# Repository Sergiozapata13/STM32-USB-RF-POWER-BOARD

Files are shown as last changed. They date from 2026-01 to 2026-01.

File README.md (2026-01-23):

# STM32-USB-RF-POWER-BOARD

## Overview
STM32-based embedded board integrating USB, RF transceiver, and regulated power supply.
Designed in KiCad with focus on signal integrity, power distribution, EMI mitigation, and
robust hardware design practices.

The project demonstrates a complete PCB design workflow, from system architecture
definition and schematic design to PCB layout and manufacturability review.

---

## System Architecture
The board integrates the following functional blocks:

- STM32 microcontroller
- USB interface for power and data communication
- nRF24L01+ 2.4 GHz RF transceiver
- Regulated 3.3 V power supply derived from USB
- SWD interface for programming and debugging

---

## Power Architecture

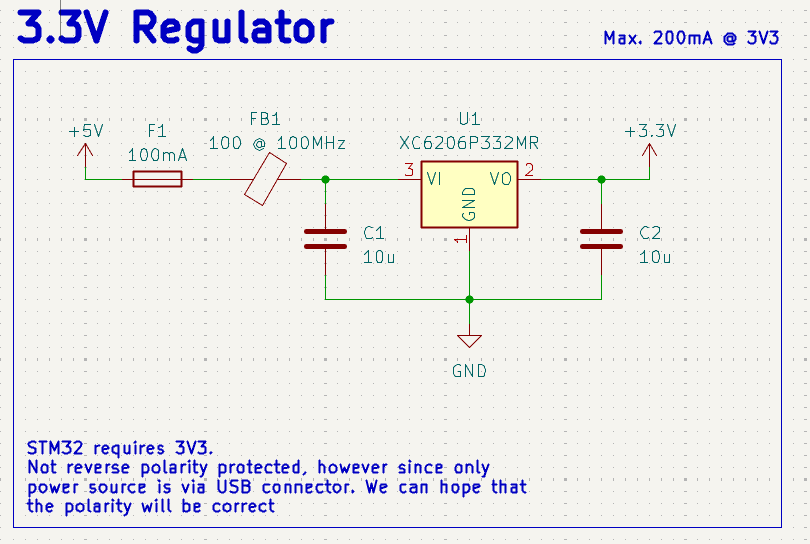
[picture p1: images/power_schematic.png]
Power architecture schematic


The board is powered exclusively from the USB 5 V rail. Input protection is provided
by a resettable fuse (100 mA) and a ferrite bead (100 Ω @ 100 MHz) to limit overcurrent
conditions and attenuate high-frequency noise coming from the USB source.

A low-dropout linear regulator (XC6206P332MR) is used to generate the 3.3 V supply
required by the STM32 microcontroller and the RF transceiver. This regulator was
selected due to its low noise characteristics and simplicity, which are well suited
for low-current embedded applications (up to 200 mA).

Bulk capacitors are placed at both the regulator input and output to ensure stability
and reduce supply ripple. Reverse polarity protection was intentionally omitted, as the
USB connector is the only intended power source for the board.

---

## USB Design

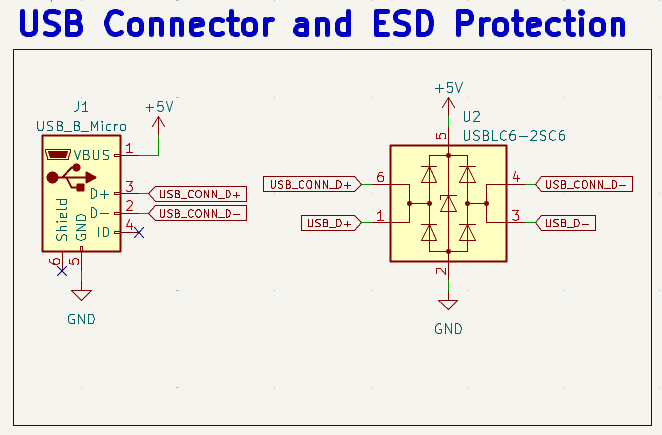
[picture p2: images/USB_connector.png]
USB connector and ESD protection


The USB interface is implemented using a Micro-USB connector and provides both power
and data connectivity. The VBUS line is used as the sole power source for the board.

Electrostatic discharge (ESD) protection is provided by a USBLC6-2SC6 device placed
between the USB connector and the microcontroller. This device protects the D+ and D−
lines against ESD events while preserving signal integrity.

USB differential data lines are routed as a matched pair and clearly labeled to support
controlled impedance routing during PCB layout. Protection components are placed close
to the connector to minimize trace length and reduce exposure to ESD events.

---

## RF Design

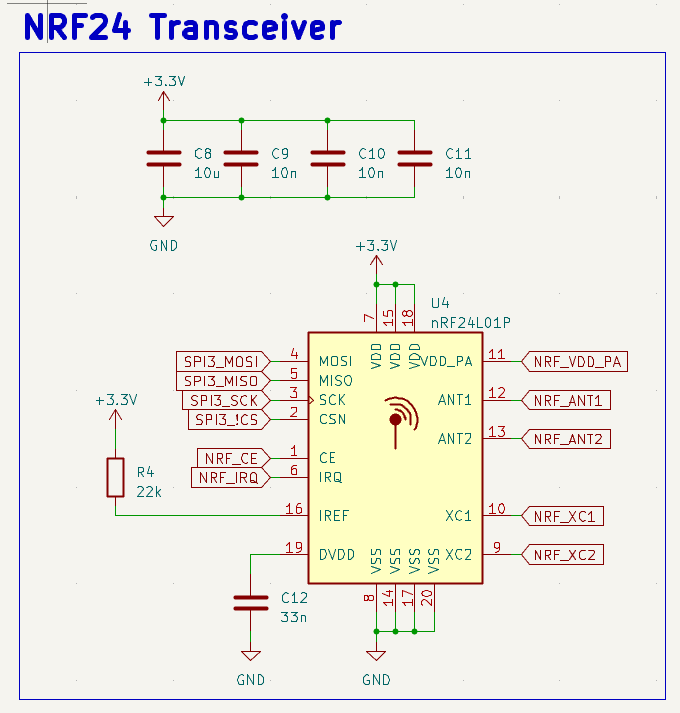
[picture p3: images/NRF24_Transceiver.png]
NRF24 transceiver schematic


The RF subsystem is based on the nRF24L01+ 2.4 GHz transceiver, interfaced with the STM32
microcontroller through an SPI interface. The device is powered from the 3.3 V rail,
with dedicated local decoupling capacitors placed close to the VDD and VDD_PA pins to
ensure stable RF operation.

Special attention was given to power integrity for the RF section by providing adequate
bulk and high-frequency decoupling and following manufacturer reference design
guidelines.

### Antenna Matching Network

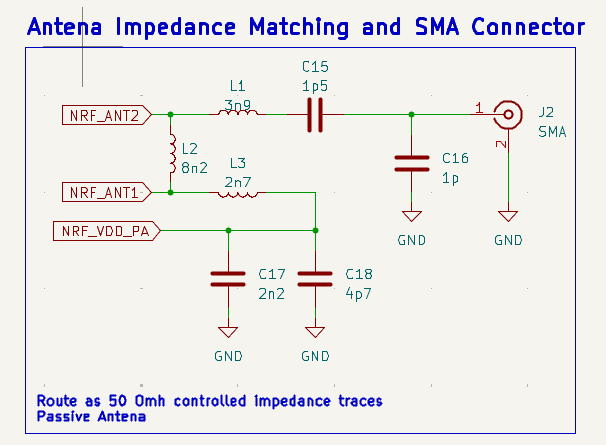
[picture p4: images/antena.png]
Antenna impedance matching network


The RF output is routed through a discrete impedance matching network before reaching
an SMA connector. The matching network is implemented using lumped inductors and
capacitors, allowing flexibility for tuning during bring-up or testing.

The RF trace is intended to be routed as a 50 Ω controlled-impedance transmission line.
Component placement and routing were optimized to keep the RF path as short and direct
as possible, minimizing losses and parasitic effects.

### RF Crystal Oscillator

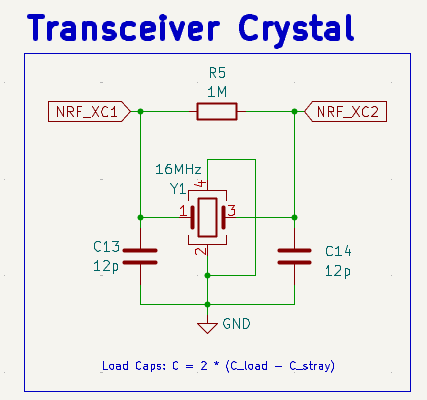
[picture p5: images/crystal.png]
RF crystal oscillator


A dedicated 16 MHz crystal oscillator is used for the RF transceiver. Load capacitors
were selected based on the required load capacitance and estimated stray capacitance
of the PCB layout. A parallel resistor is included to aid oscillator startup and
improve stability.

Crystal components are placed close to the transceiver pins with short, symmetric
traces to minimize phase noise and sensitivity to external interference.

---

## PCB Layout Strategy

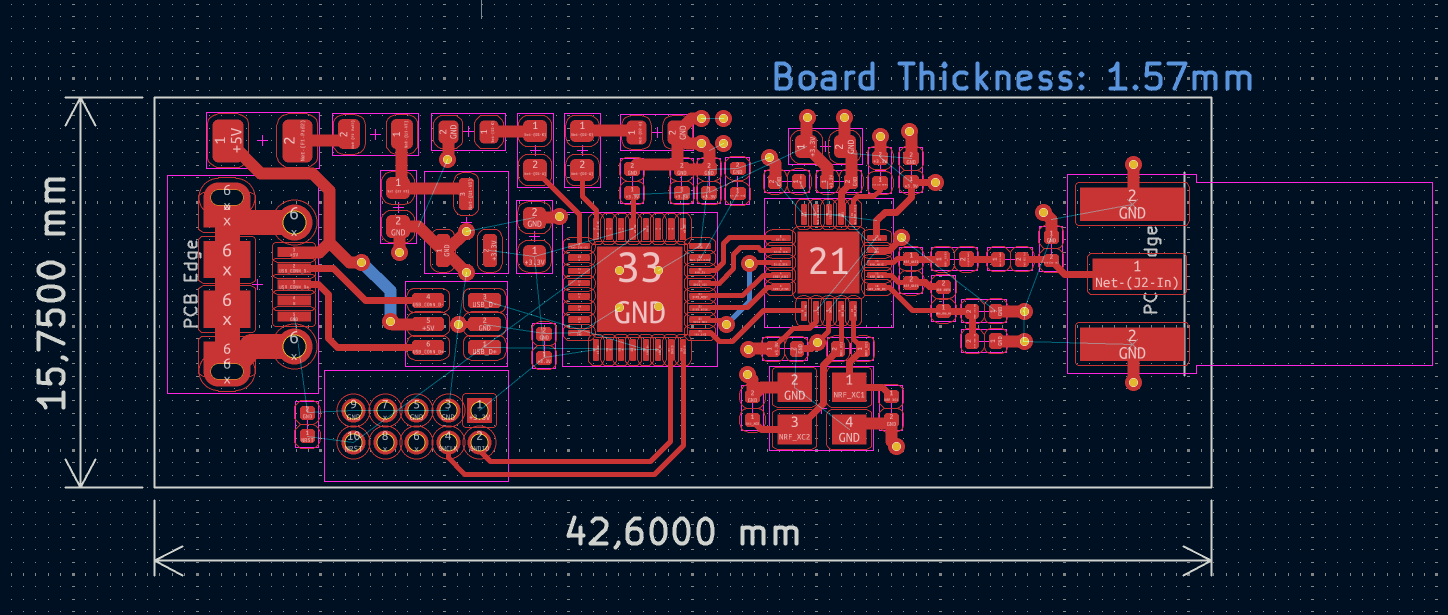
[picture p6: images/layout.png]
PCB layout overview


The PCB layout was developed with emphasis on signal integrity, power distribution,
and noise isolation between digital, RF, and power domains. Component placement was
driven by functional grouping, minimizing critical trace lengths and optimizing return
current paths.

High-frequency and noise-sensitive components, such as the RF transceiver and its
matching network, are placed close together to reduce parasitic effects. Power-related
components are grouped to form compact current loops, reducing EMI and voltage ripple.

USB differential pairs are routed together with consistent spacing and length matching,
and ground continuity is maintained under high-speed signals to ensure a clear return
path.

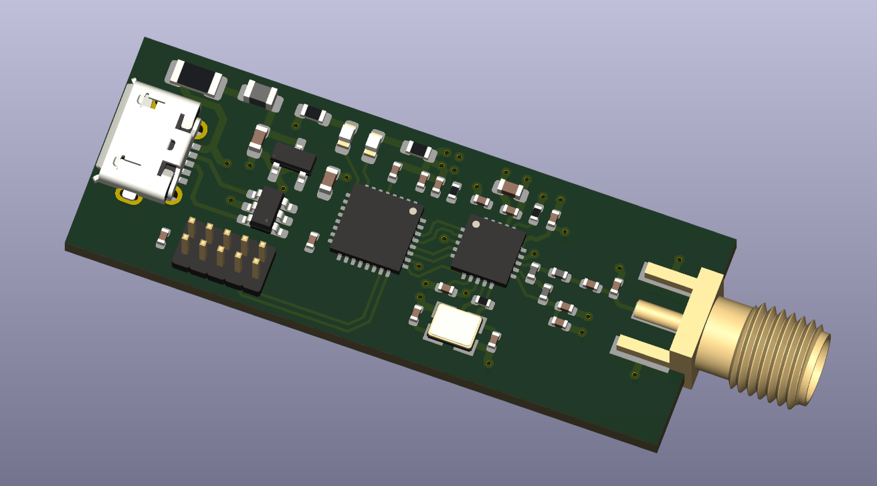
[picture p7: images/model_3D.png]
3D view of the assembled PCB


A compact board outline was selected to balance mechanical constraints, routing density,
and manufacturability.

---

## Hardware Validation and Design Status

The PCB was fully designed and reviewed at schematic and layout level; however, the
board was not manufactured or assembled.

Design validation focused on schematic correctness, component selection, and layout
best practices. Electrical rules checks (ERC) and design rule checks (DRC) were used to
verify connectivity, clearance, and manufacturability constraints.

The design is considered ready for fabrication. A bring-up and validation plan was
defined, including power rail verification, SWD programming, USB enumeration, and basic
RF communication tests.

Although physical validation was not performed, the project demonstrates a complete
end-to-end PCB design workflow, from system architecture definition to layout completion.

---

## Tools
- KiCad
- STM32CubeMX (pinout and reference configuration)

---

## Project Status
- Schematic and PCB layout completed
- Design reviewed with ERC/DRC verification
- Ready for fabrication

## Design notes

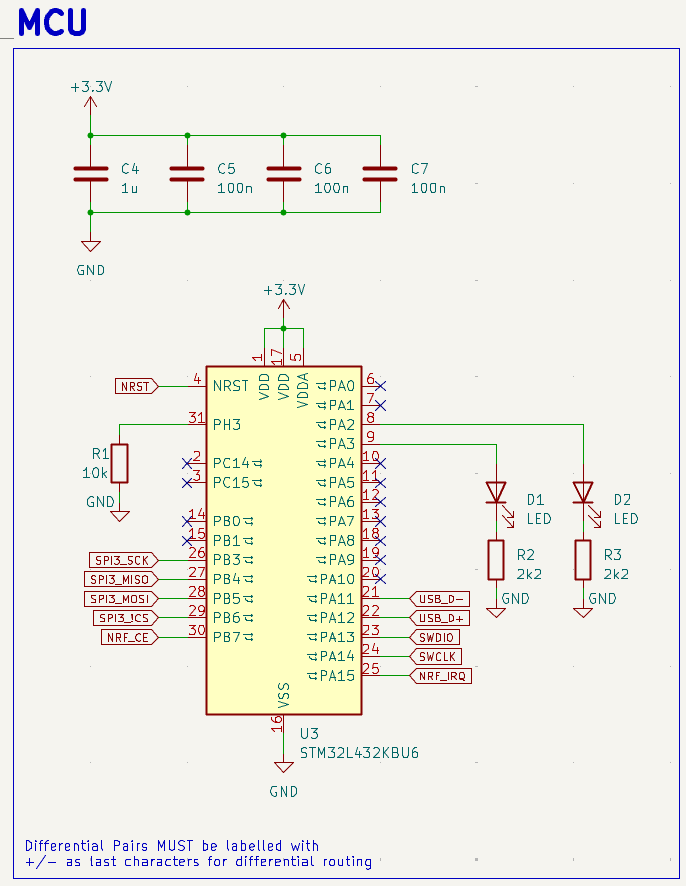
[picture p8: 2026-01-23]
images/MCU.png

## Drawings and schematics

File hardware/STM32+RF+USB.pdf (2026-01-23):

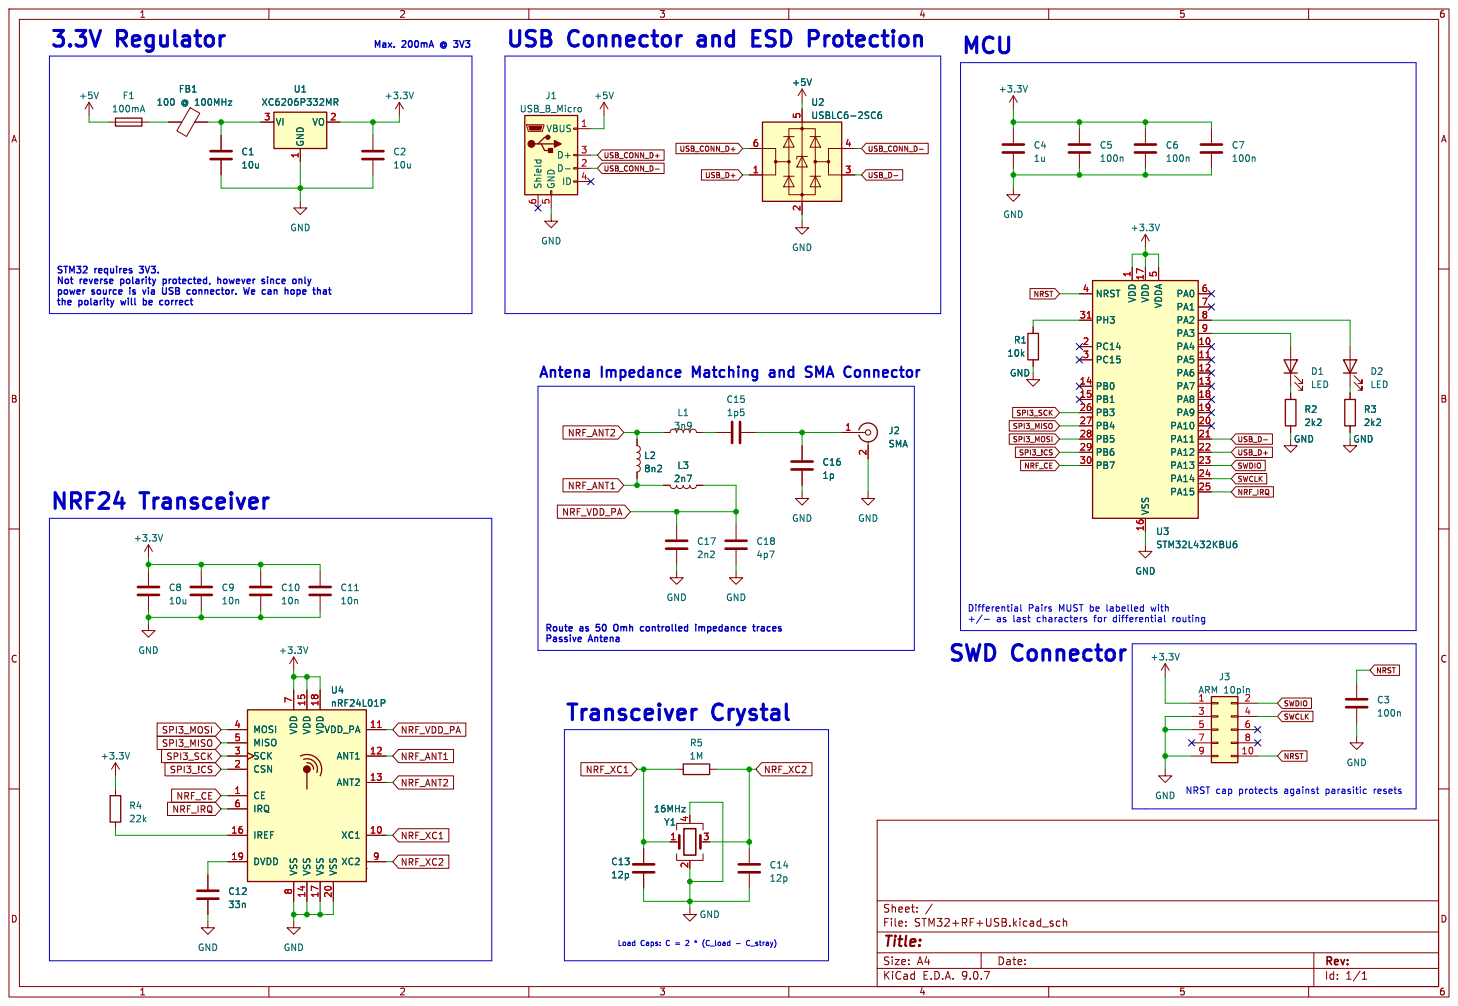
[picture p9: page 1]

USB Connector and ESD Protection

SPI3_!CS STM32 requires 3V3. Not reverse polarity protected, however since only power source is via USB connector. We can hope that

the polarity will be correct NRF24 Transceiver

8 VDD 15 VSS 14 VDD 18 VSS 17 VSS 20 VDD_PA 11 ANT1 12 ANT2 13 XC1 10 XC2 9 C12

8 VDD 15 VSS 14 VDD 18 VSS 17 VSS 20 VDD_PA 11 ANT1 12 ANT2 13 XC1 10 XC2 9 U4

Id: 1/1 Title: File: STM32+RF+USB.kicad_sch Sheet: /

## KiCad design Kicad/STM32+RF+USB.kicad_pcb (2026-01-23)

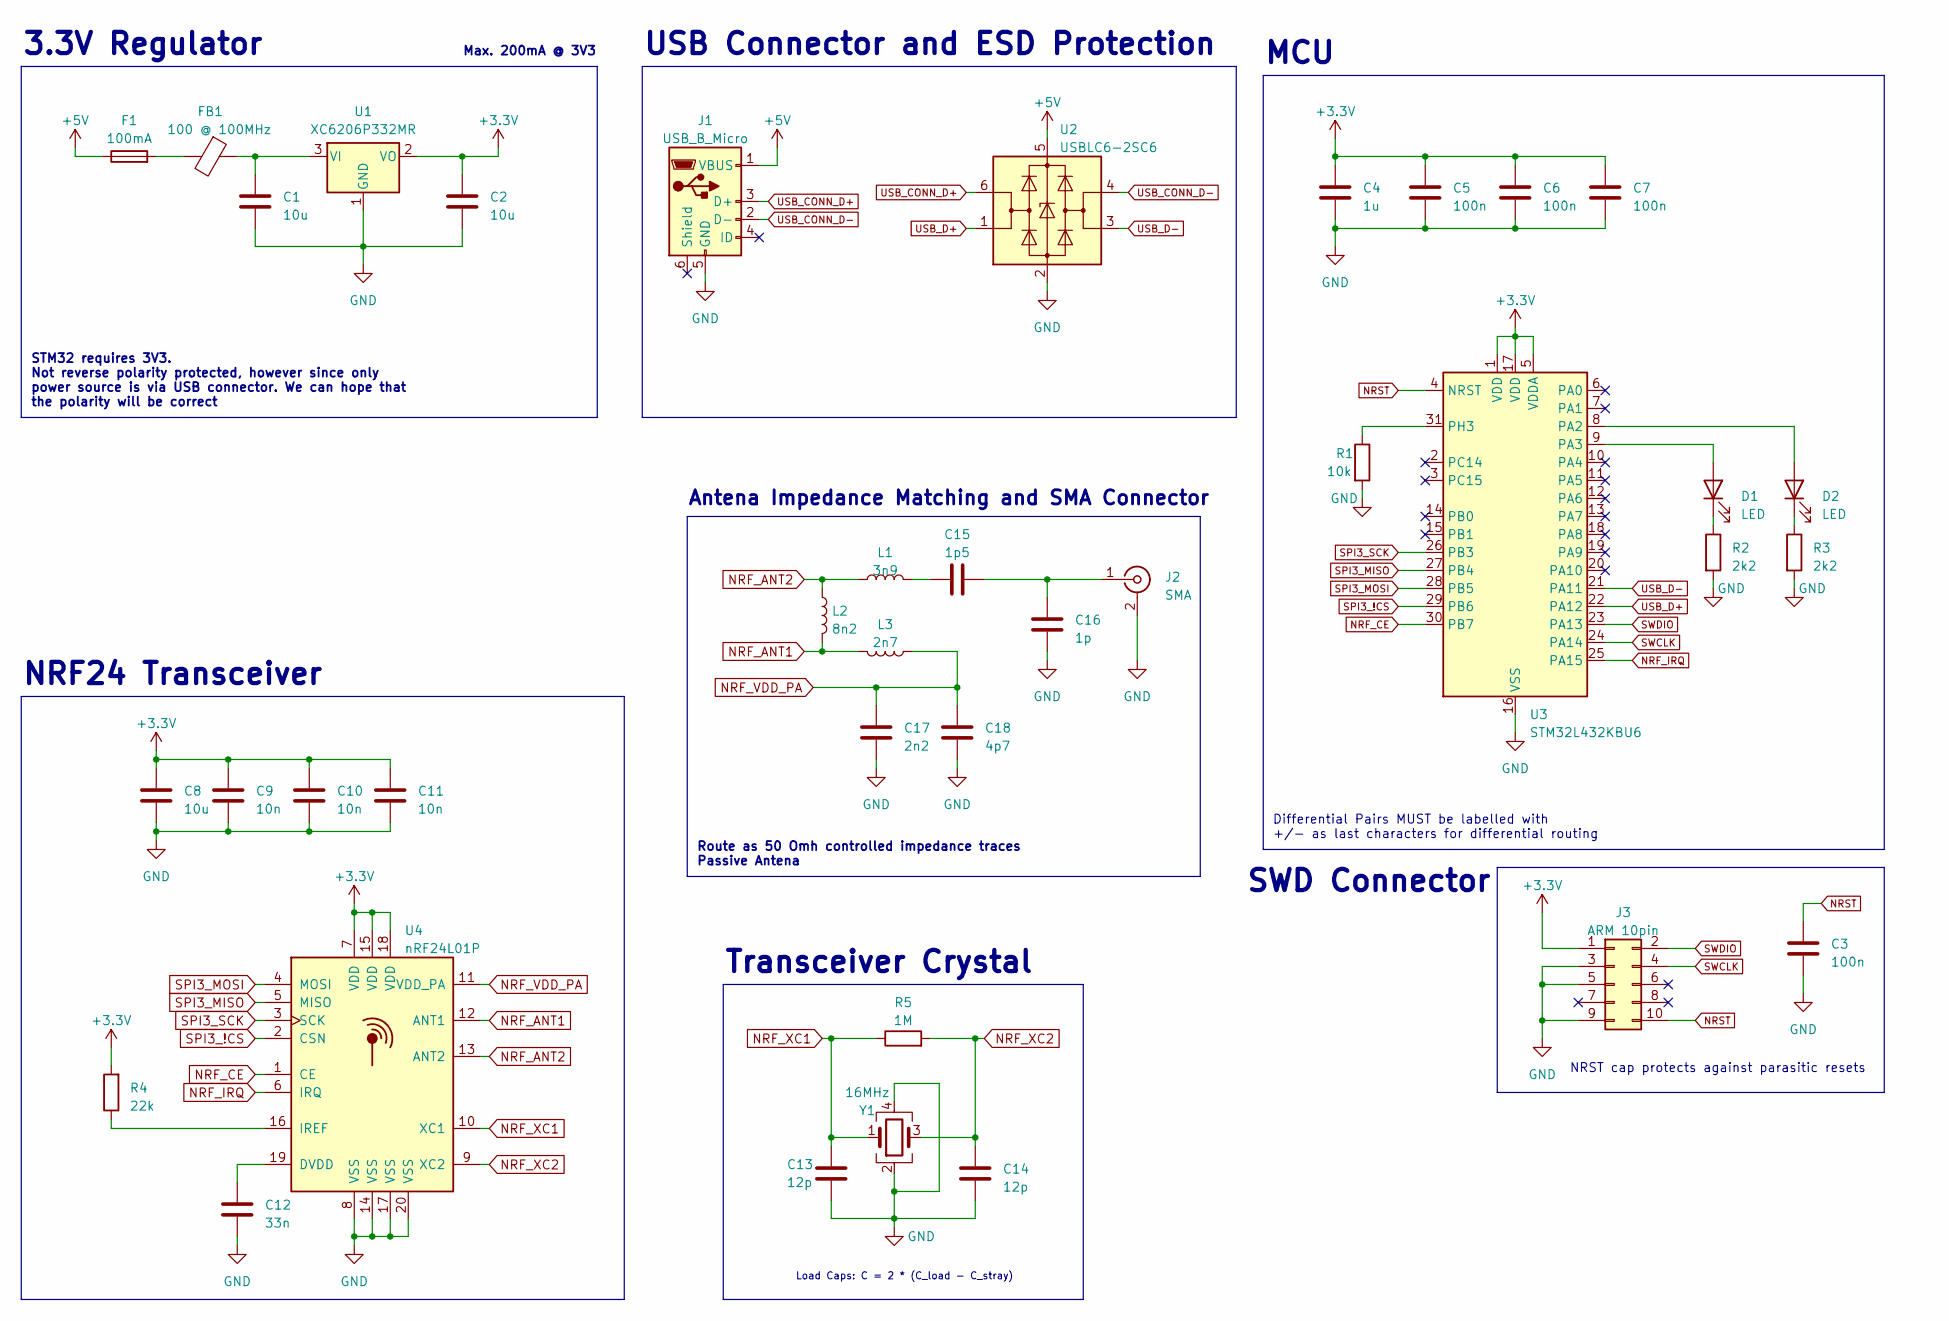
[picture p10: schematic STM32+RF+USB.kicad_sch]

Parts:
C1, C2, C8: 10u; C_0603_1608Metric
C3, C5, C6, C7: 100n; C_0402_1005Metric
C4: 1u; C_0402_1005Metric
C9, C10, C11: 10n; C_0402_1005Metric
C12: 33n; C_0402_1005Metric
C13, C14: 12p; C_0402_1005Metric
C15: 1p5; C_0402_1005Metric
C16: 1p; C_0402_1005Metric
C17: 2n2; C_0402_1005Metric
C18: 4p7; C_0402_1005Metric
D1, D2: LED; LED_0603_1608Metric
F1: 100mA; Fuse_1206_3216Metric
FB1: 100 @ 100MHz; L_0805_2012Metric
J1: USB_B_Micro; USB_Micro-B_Molex-105017-0001
J2: SMA; SMA_Samtec_SMA-J-P-X-ST-EM1_EdgeMount
J3: ARM 10pin; PinHeader_2x05_P1.27mm_Vertical
L1: 3n9; L_0402_1005Metric
L2: 8n2; L_0402_1005Metric
L3: 2n7; L_0402_1005Metric
R1: 10k; R_0402_1005Metric
R2, R3: 2k2; R_0603_1608Metric
R4: 22k; R_0402_1005Metric
R5: 1M; R_0402_1005Metric
U1: XC6206P332MR; SOT-23-3
U2: USBLC6-2SC6; SOT-23-6
U3: STM32L432KBU6; QFN-32-1EP_5x5mm_P0.5mm_EP3.45x3.45mm
U4: nRF24L01P; QFN-20-1EP_4x4mm_P0.5mm_EP2.5x2.5mm
Y1: 16MHz; Crystal_SMD_3225-4Pin_3.2x2.5mm

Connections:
+3.3V: C2.1, C4.1, C5.1, C6.1, C7.1, C8.1, C9.1, C10.1, C11.1, J3.1, R4.2, U1.2 (VO), U3.1 (VDD), U3.5 (VDDA), U3.17 (VDD), U4.7 (VDD), U4.15 (VDD), U4.18 (VDD)
+5V: F1.1, J1.1 (VBUS), U2.5 (VBUS)
GND: C1.2, C2.2, C3.2, C4.2, C5.2, C6.2, C7.2, C8.2, C9.2, C10.2, C11.2, C12.2, C13.2, C14.2, C16.1, C17.1, C18.1, J1.5 (GND), J2.2 (Ext), J3.3, J3.5, J3.9, R1.2, R2.2, R3.2, U1.1 (GND), U2.2 (GND), U3.16 (VSS), U3.32 (VSS), U3.33 (VSS), U4.8 (VSS), U4.14 (VSS), U4.17 (VSS), U4.20 (VSS), Y1.2, Y1.4
NRF_ANT1: L2.2, L3.2, U4.12 (ANT1)
NRF_ANT2: L1.1, L2.1, U4.13 (ANT2)
NRF_CE: U3.30 (PB7), U4.1 (CE)
NRF_IRQ: U3.25 (PA15), U4.6 (IRQ)
NRF_VDD_PA: C17.2, C18.2, L3.1, U4.11 (VDD_PA)
NRF_XC1: C13.1, R5.1, U4.10 (XC1), Y1.1
NRF_XC2: C14.1, R5.2, U4.9 (XC2), Y1.3
NRST: C3.1, J3.10, U3.4 (NRST)
unnamed: C15.1, L1.2
unnamed: D1.2 (A), U3.9 (PA3)
unnamed: D1.1 (K), R2.1
unnamed: D2.2 (A), U3.8 (PA2)
unnamed: D2.1 (K), R3.1
unnamed: F1.2, FB1.2
unnamed: C15.2, C16.2, J2.1 (In)
unnamed: C1.1, FB1.1, U1.3 (VI)
unnamed: R1.1, U3.31 (PH3)
unnamed: C12.1, U4.19 (DVDD)
unnamed: R4.1, U4.16 (IREF)
SPI3_!CS: U3.29 (PB6), U4.2 (CSN)
SPI3_MISO: U3.27 (PB4), U4.5 (MISO)
SPI3_MOSI: U3.28 (PB5), U4.4 (MOSI)
SPI3_SCK: U3.26 (PB3), U4.3 (SCK)
SWCLK: J3.4, U3.24 (PA14)
SWDIO: J3.2, U3.23 (PA13)
USB_CONN_D+: J1.3 (D+), U2.6 (I/O1)
USB_CONN_D-: J1.2 (D-), U2.4 (I/O2)
USB_D+: U2.1 (I/O1), U3.22 (PA12)
USB_D-: U2.3 (I/O2), U3.21 (PA11)

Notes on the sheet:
Load Caps: C = 2 * (C_load - C_stray)
Max. 200mA @ 3V3
SWD Connector
Differential Pairs MUST be labelled with +/- as last characters for differential routing
Transceiver Crystal
USB Connector and ESD Protection
STM32 requires 3V3. Not reverse polarity protected, however since only power source is via USB connector. We can hope that the polarity will be correct
Route as 50 Omh controlled impedance traces Passive Antena
MCU
Antena Impedance Matching and SMA Connector
NRST cap protects against parasitic resets
NRF24 Transceiver
3.3V Regulator

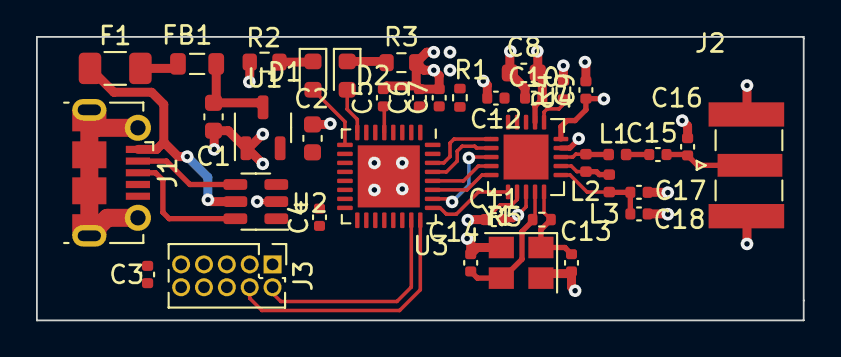
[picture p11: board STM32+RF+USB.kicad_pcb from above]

Board: 4 copper layers, 42.6 x 15.8 mm, 38 parts (0 on the bottom side), 32 nets.

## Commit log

2026-01-22 Enhance README with detailed project information
    Expanded the README with sections on system architecture, power architecture, USB design, RF design, PCB layout strategy, hardware validation, tools, and project status.
2026-01-23 Document power architecture in README
    Added detailed explanation of the power architecture, including design considerations for voltage regulation and noise performance.
2026-01-23 Refine power architecture description in README
    Updated the power architecture section for clarity and detail.
2026-01-23 Fix image link for NRF24 transceiver schematic
